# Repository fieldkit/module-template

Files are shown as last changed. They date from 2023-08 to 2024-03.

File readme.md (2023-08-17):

# Module Template
This is a template project for creating new FieldKit module hardware in Kicad.

It Has : 
* The board outline.
* A connector to attach it to a FieldKit station.
* 3.3v Regulation.
* An EEPROM to identify the module and store any calibration data.

Just clone and augment!

## License Information

> *"In the long history of humankind (and animal kind, too) those who learned to collaborate and improvise most effectively have prevailed."*
>  --**Charles Darwin**

This hardware is released under **CERN Open Hardware License Version 2 - Permissive (CERN-OHL_P)**
Obviously, it's Distributed as-is; and no warranty is given.

---
*Module Template was Designed by Bradley Gawthrop for FieldKit.*

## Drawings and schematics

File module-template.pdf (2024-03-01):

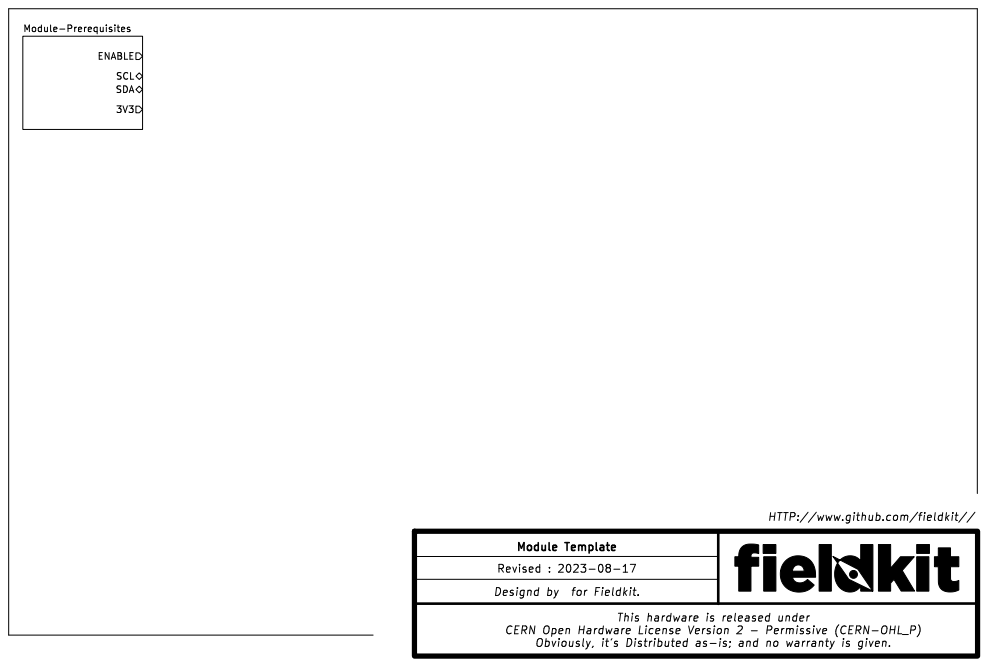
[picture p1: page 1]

SCL
HTTP://www.github.com/fieldkit// SDA

This hardware is released under

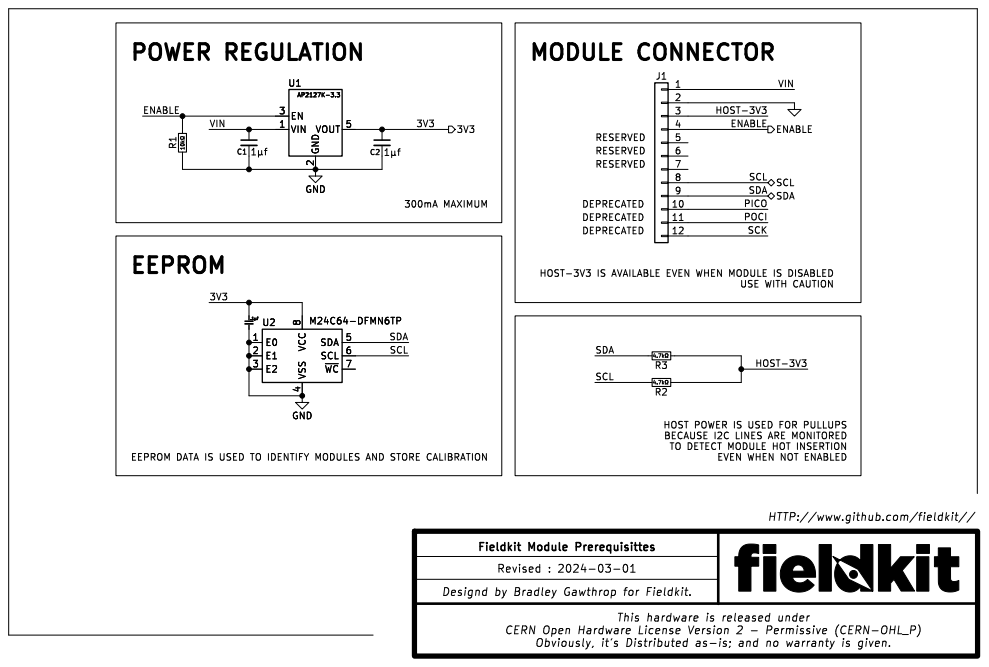
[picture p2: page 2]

USE WITH CAUTION MODULE CONNECTOR

HOST-3V3 IS AVAILABLE EVEN WHEN MODULE IS DISABLED

4 SDA 5 SCL 6 ~{WC}7 VCC

HOST POWER IS USED FOR PULLUPS
BECAUSE I2C LINES ARE MONITORED
TO DETECT MODULE HOT INSERTION

EEPROM DATA IS USED TO IDENTIFY MODULES AND STORE CALIBRATION

EVEN WHEN NOT ENABLED

HTTP://www.github.com/fieldkit//

This hardware is released under

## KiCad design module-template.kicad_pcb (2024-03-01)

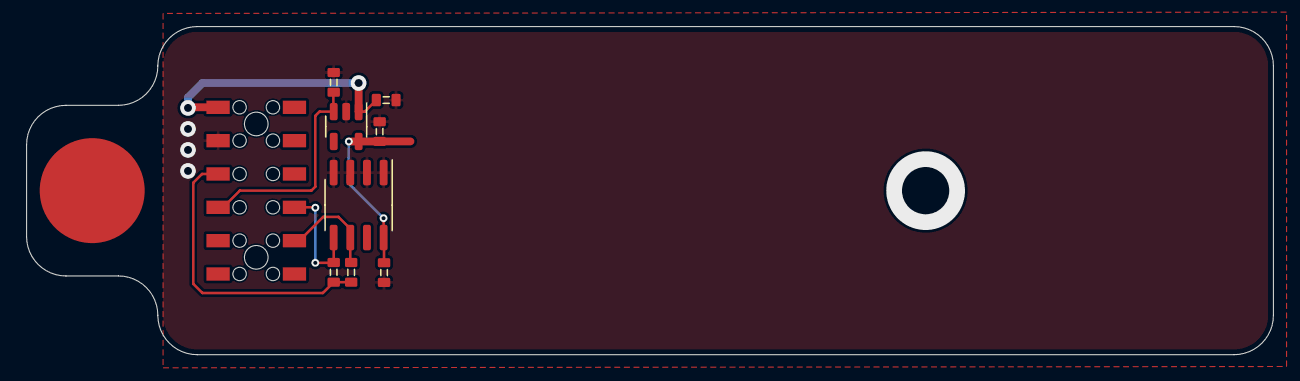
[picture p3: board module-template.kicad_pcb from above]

Board: 2 copper layers, 95.0 x 25.0 mm, 9 parts (0 on the bottom side), 7 nets.

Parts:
C1, C2: 1µf; R0603
C3: .1μf; R0603
J1: Conn_01x12; M20-7810645R
R1: 10kΩ; R0603
R2, R3: 4.7kΩ; R0603
U1: AP2127K-3.3; SOT-23-5
U2: M24C64-DFMN6TP; SOIC-8_3.9x4.9mm_P1.27mm

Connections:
/Module-Prerequisites/3V3: C2.1, C3.1, U1.5 (VOUT), U2.8 (VCC)
/Module-Prerequisites/ENABLE: J1.4, R1.1, U1.3 (EN)
/Module-Prerequisites/HOST-3V3: J1.3, R2.2, R3.2
/Module-Prerequisites/SCL: J1.8, R2.1, U2.6 (SCL)
/Module-Prerequisites/SDA: J1.9, R3.1, U2.5 (SDA)
/Module-Prerequisites/VIN: C1.1, J1.1, U1.1 (VIN)
GND: C1.2, C2.2, C3.2, J1.2, R1.2, U1.2 (GND), U2.1 (E0), U2.2 (E1), U2.3 (E2), U2.4 (VSS)

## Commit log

2023-08-16 Blank Initialization
    [module-template.kicad_pcb, module-template.kicad_sch]
2023-08-16 Added PCB Essentials
    [module-template.kicad_pcb]
2023-08-16 PCB Notes, Sheet size adjustment.
    [module-template.kicad_pcb]
2023-08-17 Schematic structure
    [module-prerequisites.kicad_sch, module-template.kicad_sch]
2023-08-17 Work on Prerequisites sheet
    [module-prerequisites.kicad_sch, module-template.kicad_sch]
2023-08-17 Finished prerequisites. Started component placement.
    [module-prerequisites.kicad_sch, module-template.kicad_pcb, module-template.kicad_sch]
2023-08-17 Board routing complete.
    [module-prerequisites.kicad_sch, module-template.kicad_pcb]
2023-08-17 Cleaning up file system.
    [module-prerequisites.kicad_sch]
2024-03-01 Small aesthetic channges, and KiCad version update.
    [module-prerequisites.kicad_sch, module-template.kicad_pcb, module-template.kicad_sch]
